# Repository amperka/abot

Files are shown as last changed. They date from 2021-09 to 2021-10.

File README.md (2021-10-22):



Amperka ROS robot "Abot" source code.

# Documentation

Detailed instructions for assembling the robot are available in Russian:

- [Как сделать робота на ROS своими руками. Часть 1: шасси и бортовая электроника](https://amperka.ru/blogs/projects/abot-robot-part-1)
- [Как сделать робота на ROS своими руками. Часть 2: дистанционное управление и навигация](https://amperka.ru/blogs/projects/abot-robot-part-2)
- [Как сделать робота на ROS своими руками. Часть 3: распознавание речи для голосового управления](https://amperka.ru/blogs/projects/abot-robot-part-3)
- [Как сделать робота на ROS своими руками. Часть 4: синтез речи и голосовое управление](https://amperka.ru/blogs/projects/abot-robot-part-4)

# Robot packages

The basis of the robot:

- `abot_description` — URDF robot description and main bringup launch files.
- `abot_driver` — Low-level drivers for working with motors and encoders on Raspberry Pi.
- `abot_control` — Robot controllers, differential drive controller.
- `abot_base` — Robot base controller.
- `abot_teleop` — Remote control of the base robot controller via the DualShock 4 joystick.
- `abot_slam` — Building 2D maps using the SLAM method and the `gmapping` package.
- `abot_navigation` — Navigation of the robot on a prepared 2D map.

Working with sound and speech on the robot:

- `abot_speech_to_text` — STT `pocketsphinx` ROS wrapper.
- `abot_text_to_speech` — TTS ROS wrappers: `RHVoice`, `festival`, AWS Polly.
- `abot_text_to_speech` — Voice control of the robot. Voice control of the navigation stack.

# Software requirements

Robot running on Ubuntu 20.04.2.0 Server arm64 and ROS Noetic and Raspberry Pi 4 B 4 Gb.

## Basis part requirements

Necessary software to run the main part of the project:

- [WiringPi](https://github.com/WiringPi/WiringPi)
- [ds4drv](https://github.com/naoki-mizuno/ds4drv)

ROS packages:

```bash
ros-noetic-gmapping
ros-noetic-joy
ros-noetic-pid
ros-noetic-map-server
ros-noetic-navigation
```

## Sound part requirements

Necessary software to run the sound part of the project:

- [GStreamer](https://en.wikipedia.org/wiki/GStreamer)
- [pocketsphinx](https://github.com/cmusphinx/pocketsphinx)
- [ru4sphinx](https://github.com/zamiron/ru4sphinx)
- [WiringPi](https://github.com/WiringPi/WiringPi)
- [TroykaHatCpp](https://github.com/amperka/TroykaHatCpp)
- [festival](https://github.com/festvox/festival)
- [RHVoice](https://github.com/RHVoice/RHVoice)
- [boto3](https://github.com/boto/boto3)
- [sox](https://github.com/chirlu/sox)

ROS packages:

```bash
ros-noetic-audio-common
ros-noetic-navigation
```

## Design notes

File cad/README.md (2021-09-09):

# Версии робота

- `ABOT_V1` - Робот первой версии. Шасси Turtle, панель Raspberry, панель лидара. Дизайн робота на момент публикации первой статьи.
- `ABOT_V2` - Робот второй версии. Шасси Turtle, панель Raspberry, панель звука, панель лидара. Дизайн робота на момент публикации второй статьи.

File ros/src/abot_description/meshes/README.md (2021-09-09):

# Версии MESH моделей

В этой папке находятся MESH модели одной из версий робота:

- `v1` - STL файлы для визуализации робота первой версии. Шасси Turtle, панель Raspberry, панель лидара.
- `v2` - STL файлы для визуализации робота второй версии. Шасси Turtle, панель Raspberry, панель звука, панель лидара.

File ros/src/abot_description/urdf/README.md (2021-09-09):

# Версии URDF описания

В этой папке находится URDF описание одной из версий робота:

- `v1` - URDF описание робота первой версии. Шасси Turtle, панель Raspberry, панель лидара.
- `v2` - URDF описание робота второй версии. Шасси Turtle, панель Raspberry, панель звука, панель лидара.

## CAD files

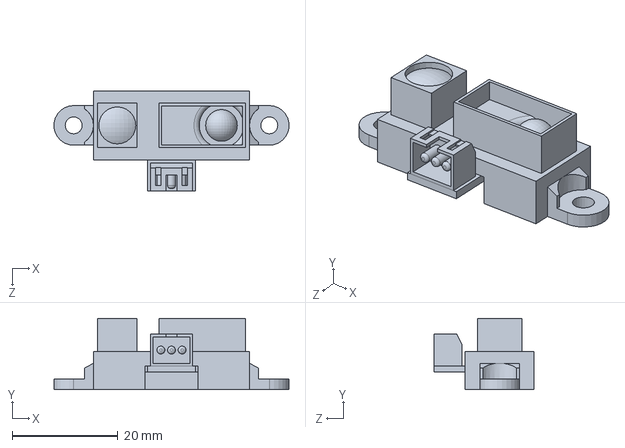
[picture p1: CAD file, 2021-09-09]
cad/SENSORS/SHARP_IR/GP2Y0A41SK0F_AXIS_FRAME.SLDASM
44.4 x 13.5 x 18.9 mm

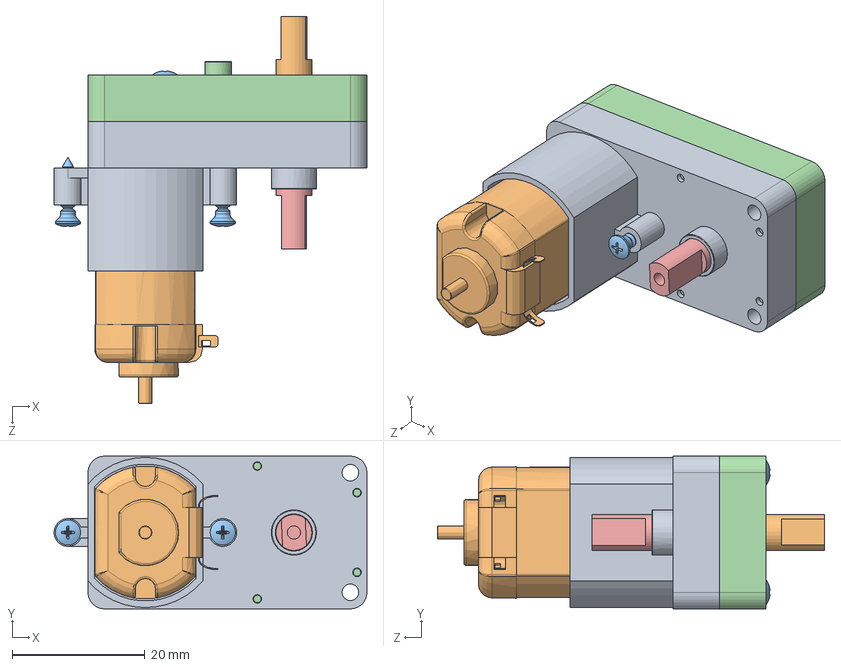
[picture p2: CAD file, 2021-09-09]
cad/MOTORS/TT_ANGLE_MOTOR.SLDASM
47.1 x 23.0 x 58.3 mm

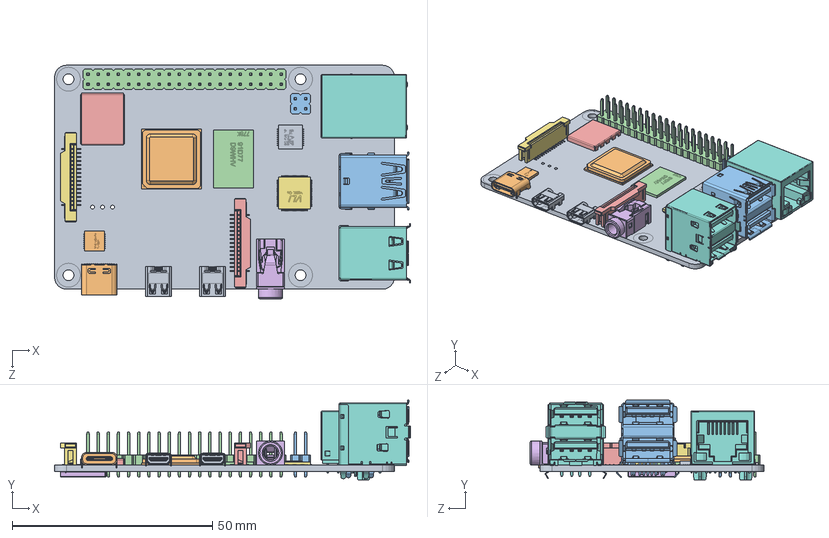
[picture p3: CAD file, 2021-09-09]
cad/ELECTRONICS/RPI/RPI/RP_4_DUMMY.SLDASM
89.0 x 19.9 x 58.4 mm
PCB, RPi4ModelB-1
Broadcom BCM2711B0 CPU, RPi4ModelB-1
2.54 mm DUPONT MALE PIN HEADER, POE, 2X2, RPi4ModelB-1
2.54 mm DUPONT MALE PIN HEADER, IO, 2X20, RPi4ModelB-1
Camera Connector, RPi4ModelB-1
Microphone Plug, RPi4ModelB-1
Display Connector, RPi4ModelB-1
Gigabit Ethernet Port, RPi4ModelB-1
Female Micro HDMI Connector, RPi4ModelB-1 x 2
Female USB Type C Connector, RPi4ModelB-1
2X USB3.0 PORTS, RPi4ModelB-1
91D77 D9WHV 778K, 4 GB LPDDR4 SDRAM, RPi4ModelB-1
Cypress CYW43455 Wireless Module Cover, RPi4ModelB-1
SD Card Slot, RPi4ModelB-1
VIA VL805 PCIe USB 3.0 controller, RPi4ModelB-1
2X USB2.0 PORTS, RPi4ModelB-1
Broadcom BCM54213PE Gigabit Ethernet Transceiver, RPi4ModelB-1
MxL7704 Universal PMIC, RPi4ModelB-1

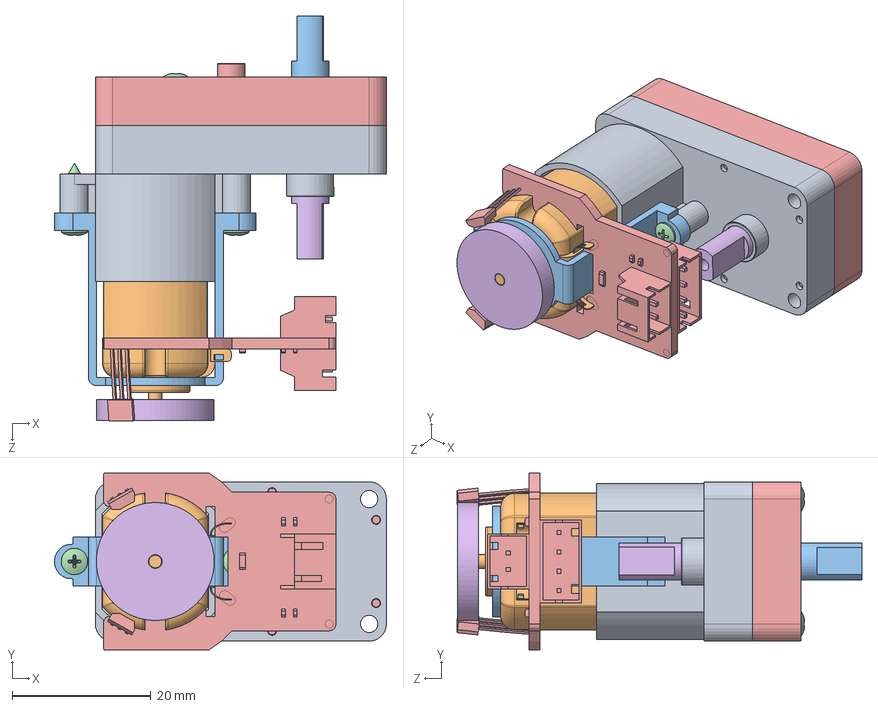
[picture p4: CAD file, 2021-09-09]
cad/MOTORS/TT_ANGLE_MOTOR_WITH_ENCODER.SLDASM
47.9 x 25.5 x 58.4 mm

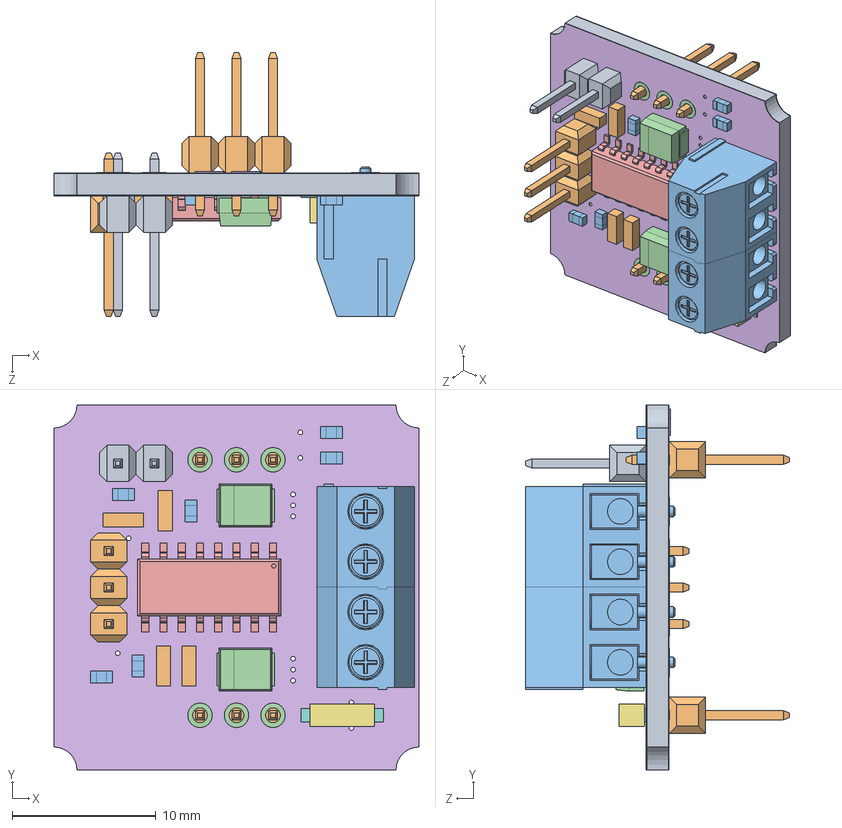
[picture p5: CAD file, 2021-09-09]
cad/ELECTRONICS/AMPERKA/TROYKA_AMPLIFIER_D/TROYKA_AMPLIFIER_D.SLDASM
25.4 x 25.4 x 18.4 mm
TROYKA_AMPLIFIER_D_Board
TROYKA_AMPLIFIER_D_C0603 x 4
TROYKA_AMPLIFIER_D_R0603 x 6
TROYKA_AMPLIFIER_D_SMC_B x 2
TROYKA_AMPLIFIER_D_SO16_SHORTPADS
TROYKA_AMPLIFIER_D_J0402 x 2
TROYKA_AMPLIFIER_D_Body
TROYKA_AMPLIFIER_D_Pins
TROYKA_AMPLIFIER_D_Model
TROYKA_AMPLIFIER_D_Model (1) x 3
TROYKA_AMPLIFIER_D_14420348.f3d x 2
TROYKA_AMPLIFIER_D_1-copper
TROYKA_AMPLIFIER_D_16-copper
TROYKA_AMPLIFIER_D_1-soldermask_1
TROYKA_AMPLIFIER_D_16-soldermask_1

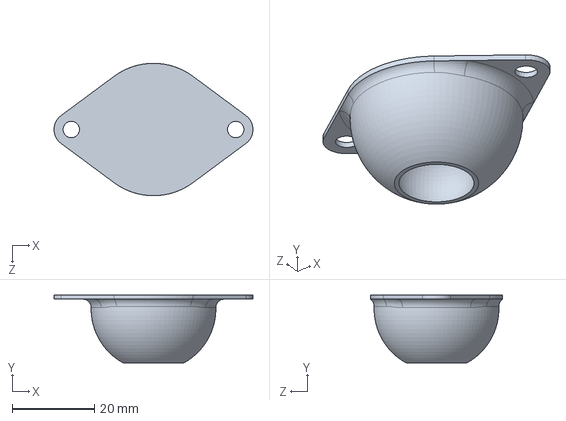
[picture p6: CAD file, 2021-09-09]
cad/CHASSIS/CASTER_WHEEL_CASE.SLDPRT
48.4 x 16.5 x 32.2 mm

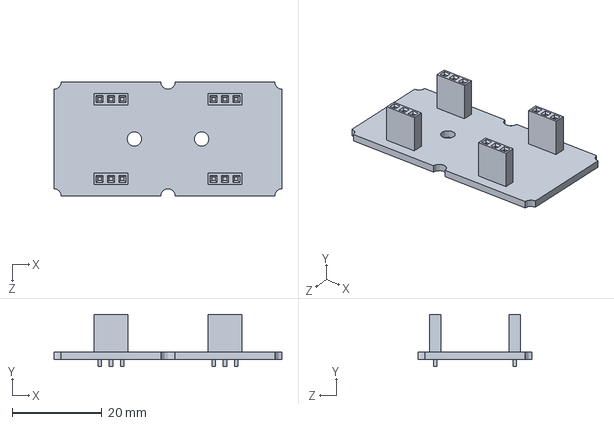
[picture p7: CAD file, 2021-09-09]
cad/ELECTRONICS/AMPERKA/TROYKA_PAD_X2_DUMMY.SLDPRT
50.8 x 11.6 x 25.4 mm

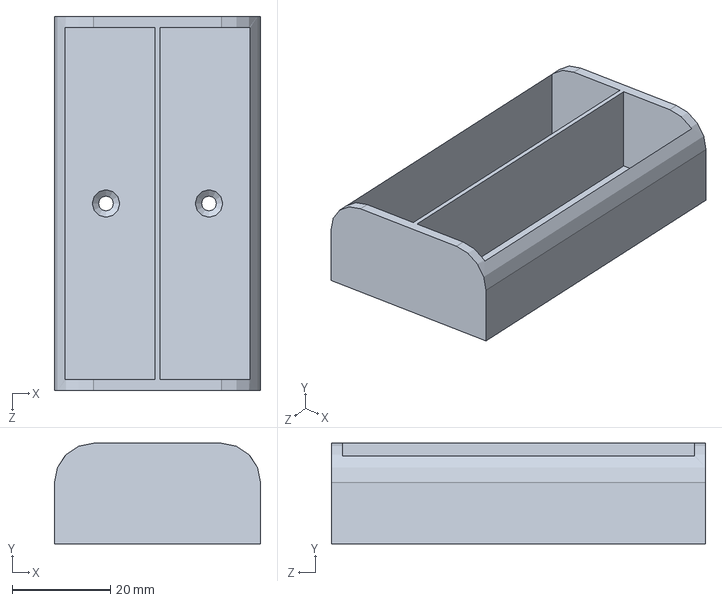
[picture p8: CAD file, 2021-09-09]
cad/ELECTRONICS/BATTERY_HOLDERS/COMMON_18650_BATTERY_HOLDER_DUMMY.SLDPRT
42.0 x 20.5 x 76.3 mm

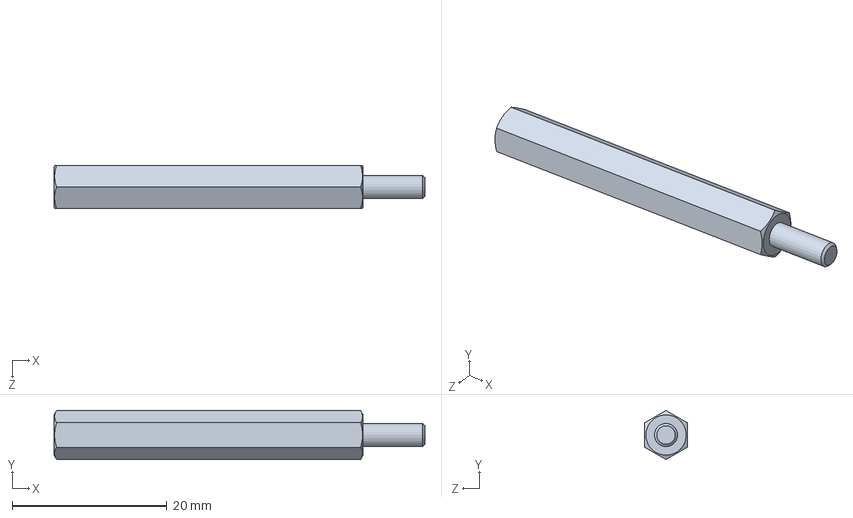
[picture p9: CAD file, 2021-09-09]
cad/METALWARE/STANDOFF_M3_40.SLDPRT
48.0 x 6.35 x 5.50 mm

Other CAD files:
cad/ELECTRONICS/AMPERKA/TROYKA_AMPLIFIER_D/TROYKA_AMPLIFIER_D__PIN_1X3.sldasm
cad/ELECTRONICS/AMPERKA/TROYKA_AMPLIFIER_D/TROYKA_AMPLIFIER_D__INDC4509X190N.sldasm
cad/ELECTRONICS/AMPERKA/TROYKA_AMPLIFIER_D/TROYKA_AMPLIFIER_D__PIN_1X3-1.sldasm
cad/ELECTRONICS/AMPERKA/TROYKA_AMPLIFIER_D/TROYKA_AMPLIFIER_D__Packages.sldasm
cad/ELECTRONICS/AMPERKA/TROYKA_AMPLIFIER_D/TROYKA_AMPLIFIER_D__SDR0302.sldasm
cad/ELECTRONICS/AMPERKA/TROYKA_AMPLIFIER_D/TROYKA_AMPLIFIER_D__PIN_1X3-2.sldasm
cad/ELECTRONICS/AMPERKA/TROYKA_AMPLIFIER_D/TROYKA_AMPLIFIER_D__PIN_1X2.sldasm
cad/ELECTRONICS/AMPERKA/TROYKA_AMPLIFIER_D/TROYKA_AMPLIFIER_D__BLM41PG102SZ1B v1.sldasm
cad/ELECTRONICS/RPI/RPI/Display Connector, RPi4ModelB-1.sldprt
cad/CHASSIS/CASTER_WHEEL_BALL.SLDPRT
cad/CHASSIS/LOWER_PLATE.SLDPRT
cad/CHASSIS/UPPER_PLATE.SLDPRT
cad/CHASSIS/WHEEL_D65_W26.SLDPRT
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

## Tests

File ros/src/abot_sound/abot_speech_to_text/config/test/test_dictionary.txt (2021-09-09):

робот
включи
выключи
зеленый
красный
светодиод
все
светодиоды
установи
яркость
красного
зеленого
светодиода
ноль
десять
двадцать
тридцать
сорок
пятьдесят
шестьдесят
семьдесят
восемьдесят
девяносто
сто

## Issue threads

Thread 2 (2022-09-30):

Не запускается abot_drivers

vdunaev, 2022-09-30:
Добрый день.
Надеюсь на вашу помощь.

Следую туториалу на amperka. Пытаюсь запустить двигатели в первый раз. Значения с датчика холла приходят, скорость, углы - все ОК.

При попытке запустить двигатели и задать скорость ничего не происходит.
А в консоли на Raspberi Pi warning:

Waiting for first setpoint message

Судя по исходникам библиотеки это из-за
!ros::topic::waitForMessage<std_msgs::Float64>(setpoint_topic_, [ros::Duration])

Уже пробовал remap менять, вручную задавать разные значения
Ничего не помогает

gabbapeople, 2022-10-01:
Привет!

Можно чуток подробнее.
- Какая OS? Какая распберри?
- Как пытаетесь запустить моторы? Каким кодом, библиотекой / нодой (через wiringPi?)
- Какой драйвер моторов (плата)
- Было бы круто более подробный лог из консоли или даже скрин

vdunaev, 2022-10-03:
@gabbapeople спасибо за ответ

- Ubuntu 20.04.5
- Raspberry Pi 4 Model B (4gb)
- Пакет 1 в 1 из репозитория abot_driver (кроме пока лидара)
`<launch>
	<node name="encoders" pkg="abot_driver" type="encoders" output="screen" />
	<node name="dc_motors" pkg="abot_driver" type="dc_motors" output="screen" />
	<include file="$(find abot_driver)/launch/abot_pid.launch" />
</launch>`
- Драйвер мотора как в статье - двухканальный Н-мост (Troyka-модуль), Troyka HAT

vdunaev, 2022-10-03:
Все шаги 1 в 1 как в статье
Значения с датчика холла приходят корректно

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

gabbapeople, 2022-10-03:
@vdunaev ну так по виду все работает.

Setpoint Warning - это пид контроллер ждет первое значение целевой скорости.
Попробуйте вручную запаблишить скорость в топики `/abot/right_wheel/target_velocity` `/abot/left_wheel/target_velocity` из консоли командой `rostopic pub --once  /abot/right_wheel/target_velocity std_msgs/Float64` и далее значение скорости в формате yaml.  Можно после  `std_msgs/Float64` нажать TAB  и ROS cкопипастит шаблон синтаксиса.

vdunaev, 2022-10-03:
Получилось только если сделать это на самом распбери.
Странно что в rqt топики видны, паблиш работает, но сообщения по факту не долетают до робота

vdunaev, 2022-10-03:
@gabbapeople большое спасибо.
Проблема была в том, что я запускаю мастер в докере (т.к. ubuntu 22 версии на локальной машине)
И не прокинул туда ROS_HOSTNAME, ROS_IP

А лишь только ROS_MASTER_URI

docker run -it --name ros --network=host --rm --env="LIBGL_ALWAYS_SOFTWARE=1" --env="ROS_MASTER_URI=http://robot-user:11311" --env="ROS_HOSTNAME=robot-user" --env="ROS_IP=192.168.0.237"  --env="DISPLAY" --env="QT_X11_NO_MITSHM=1" --volume="/tmp/.X11-unix:/tmp/.X11-unix:rw" --volume="/home/vasia/Robots/ros_src:/opt/ros/src" osrf/ros:noetic-desktop-full

В итоге заработало!

Closed 2022-10-03.

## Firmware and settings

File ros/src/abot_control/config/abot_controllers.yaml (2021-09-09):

joint_state_controller:
  type: joint_state_controller/JointStateController
  publish_rate: 100

mobile_abot:
  type : "diff_drive_controller/DiffDriveController"
  left_wheel: 'left_wheel_to_base'
  right_wheel: 'right_wheel_to_base'
  publish_rate: 100.0
  pose_covariance_diagonal: [0.001, 0.001, 1000000.0, 1000000.0, 1000000.0, 1000.0]
  twist_covariance_diagonal: [0.001, 0.001, 1000000.0, 1000000.0, 1000000.0, 1000.0]

  wheel_separation_multiplier: 1.0 # default: 1.0
  wheel_radius_multiplier    : 1.0 # default: 1.0
  cmd_vel_timeout: 1.0
  base_frame_id: base_footprint
  linear:
    x:
      has_velocity_limits : true
      max_velocity : 0.6 # m/s
      has_acceleration_limits: true
      max_acceleration : 6.0 # m/s^2
  angular:
    z:
      has_velocity_limits : true
      max_velocity : 4.71 # rad/s
      has_acceleration_limits: true
      max_acceleration : 9.42 # rad/s^2
  enable_odom_tf: true

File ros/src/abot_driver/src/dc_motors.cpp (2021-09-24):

#include "dc_motor_wiring_pi.hpp"
#include <std_msgs/Float64.h>

#define MOTOR_1_PIN_D 4 // Wiring pi 7 = BCM 4
#define MOTOR_1_PIN_E 18 // Wiring pi 1 = BCM 18
#define MOTOR_2_PIN_D 12 // Wiring pi 26 = BCM 12
#define MOTOR_2_PIN_E 13 // Wiring pi 23 = BCM 13

DCMotorWiringPi left_dc_motor(MOTOR_1_PIN_D, MOTOR_1_PIN_E);
DCMotorWiringPi right_dc_motor(MOTOR_2_PIN_D, MOTOR_2_PIN_E);

void leftMotorCallback(const std_msgs::Float64& msg) {
	int16_t pwm = msg.data * 100;
	if (pwm > 0) {
		left_dc_motor.ccw(abs(pwm));
	} else if (pwm < 0) {
		left_dc_motor.cw(abs(pwm));
	} else if (pwm == 0) {
		left_dc_motor.stop();
	}
}

void rightMotorCallback(const std_msgs::Float64& msg) {
	int16_t pwm = msg.data * 100;
	if (pwm > 0) {
		right_dc_motor.ccw(abs(pwm));
	} else if (pwm < 0) {
		right_dc_motor.cw(abs(pwm));
	} else if (pwm == 0) {
		right_dc_motor.stop();
	}
}

int main(int argc, char** argv) {
	ros::init(argc, argv, "dc_motors");
	ros::NodeHandle node;
	ros::Subscriber left_motor_target_vel_sub = node.subscribe("/abot/left_wheel/pwm", 1, &leftMotorCallback);
	ros::Subscriber right_motor_target_vel_sub = node.subscribe("/abot/right_wheel/pwm", 1, &rightMotorCallback);
	ros::spin();
	return 0;
}

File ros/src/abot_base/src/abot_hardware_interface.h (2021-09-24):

#ifndef ABOT_HARDWARE_INTERFACE_HPP_
#define ABOT_HARDWARE_INTERFACE_HPP_

#include <boost/assign/list_of.hpp>
#include <sstream>
#include <std_msgs/Float64.h>
#include <std_srvs/Empty.h>

#include <controller_manager/controller_manager.h>
#include <hardware_interface/joint_command_interface.h>
#include <hardware_interface/joint_state_interface.h>
#include <hardware_interface/robot_hw.h>
#include <ros/console.h>
#include <ros/ros.h>

class AbotHardwareInterface : public hardware_interface::RobotHW {
public:
	AbotHardwareInterface(ros::NodeHandle node, ros::NodeHandle private_node, double target_max_wheel_angular_speed);

	void updateJointsFromHardware(const ros::Duration& period);
	void writeCommandsToHardware();

private:
	ros::NodeHandle _node;
	ros::NodeHandle _private_node;

	hardware_interface::JointStateInterface _joint_state_interface;
	hardware_interface::VelocityJointInterface _velocity_joint_interface;

	ros::Subscriber _left_wheel_angle_sub;
	ros::Subscriber _right_wheel_angle_sub;
	ros::Publisher _left_wheel_vel_pub;
	ros::Publisher _right_wheel_vel_pub;

	struct Joint {
		double position;
		double position_offset;
		double velocity;
		double effort;
		double velocity_command;

		Joint()
			: position(0)
			, velocity(0)
			, effort(0)
			, velocity_command(0) { }
	} _joints[2];

	double _left_wheel_angle;
	double _right_wheel_angle;
	double _max_wheel_angular_speed;

	void registerControlInterfaces();
	void leftWheelAngleCallback(const std_msgs::Float64& msg);
	void rightWheelAngleCallback(const std_msgs::Float64& msg);
	void limitDifferentialSpeed(double& diff_speed_left_side, double& diff_speed_right_side);
};

AbotHardwareInterface::AbotHardwareInterface(ros::NodeHandle node, ros::NodeHandle private_node, double target_max_wheel_angular_speed)
	: _node(node)
	, _private_node(private_node)
	, _max_wheel_angular_speed(target_max_wheel_angular_speed) {
	registerControlInterfaces();

	_left_wheel_vel_pub = _node.advertise<std_msgs::Float64>("/abot/left_wheel/target_velocity", 1);
	_right_wheel_vel_pub = _node.advertise<std_msgs::Float64>("/abot/right_wheel/target_velocity", 1);
	_left_wheel_angle_sub = _node.subscribe("abot/left_wheel/angle", 1, &AbotHardwareInterface::leftWheelAngleCallback, this);
	_right_wheel_angle_sub = _node.subscribe("abot/right_wheel/angle", 1, &AbotHardwareInterface::rightWheelAngleCallback, this);
}

void AbotHardwareInterface::writeCommandsToHardware() {
	double diff_angle_speed_left = _joints[0].velocity_command;
	double diff_angle_speed_right = _joints[1].velocity_command;

	limitDifferentialSpeed(diff_angle_speed_left, diff_angle_speed_right);

	std_msgs::Float64 left_wheel_vel_msg;
	std_msgs::Float64 right_wheel_vel_msg;

	left_wheel_vel_msg.data = diff_angle_speed_left;
	right_wheel_vel_msg.data = diff_angle_speed_right;

	_left_wheel_vel_pub.publish(left_wheel_vel_msg);
	_right_wheel_vel_pub.publish(right_wheel_vel_msg);
}

void AbotHardwareInterface::updateJointsFromHardware(const ros::Duration& period) {
	double delta_left_wheel = _left_wheel_angle - _joints[0].position - _joints[0].position_offset;
	double delta_right_wheel = _right_wheel_angle - _joints[1].position - _joints[1].position_offset;

	if (std::abs(delta_left_wheel) < 1) {
		_joints[0].position += delta_left_wheel;
		_joints[0].velocity = delta_left_wheel / period.toSec();
	} else {
		_joints[0].position_offset += delta_left_wheel;
	}

	if (std::abs(delta_right_wheel) < 1) {
		_joints[1].position += delta_right_wheel;
		_joints[1].velocity = delta_right_wheel / period.toSec();
	} else {
		_joints[1].position_offset += delta_right_wheel;
	}
}

void AbotHardwareInterface::registerControlInterfaces() {
	ros::V_string joint_names = boost::assign::list_of("left_wheel_to_base")("right_wheel_to_base");

	for (unsigned int i = 0; i < joint_names.size(); i++) {
		hardware_interface::JointStateHandle joint_state_handle(joint_names[i], &_joints[i].position, &_joints[i].velocity, &_joints[i].effort);
		_joint_state_interface.registerHandle(joint_state_handle);

		hardware_interface::JointHandle joint_handle(joint_state_handle, &_joints[i].velocity_command);
		_velocity_joint_interface.registerHandle(joint_handle);
	}
	registerInterface(&_joint_state_interface);
	registerInterface(&_velocity_joint_interface);
}

void AbotHardwareInterface::leftWheelAngleCallback(const std_msgs::Float64& msg) {
	_left_wheel_angle = msg.data;
}

void AbotHardwareInterface::rightWheelAngleCallback(const std_msgs::Float64& msg) {
	_right_wheel_angle = msg.data;
}

void AbotHardwareInterface::limitDifferentialSpeed(double& diff_speed_left_side, double& diff_speed_right_side) {
	double large_speed = std::max(std::abs(diff_speed_left_side), std::abs(diff_speed_right_side));
	if (large_speed > _max_wheel_angular_speed) {
		diff_speed_left_side *= _max_wheel_angular_speed / large_speed;
		diff_speed_right_side *= _max_wheel_angular_speed / large_speed;
	}
}

#endif // ABOT_HARDWARE_INTERFACE_HPP_

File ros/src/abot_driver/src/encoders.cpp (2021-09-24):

#include "encoder_wiring_pi.hpp"
#include <chrono>
#include <std_msgs/Float64.h>

typedef boost::chrono::steady_clock time_source;

class EncodersPair {
public:
	EncodersPair(double update_rate);

private:
	ros::NodeHandle node;

	ros::Publisher left_wheel_angle_pub;
	ros::Publisher right_wheel_angle_pub;
	ros::Publisher left_wheel_velocity_pub;
	ros::Publisher right_wheel_velocity_pub;

	ros::Timer encoders_timer;

	std_msgs::Float64 left_wheel_angle_msg;
	std_msgs::Float64 right_wheel_angle_msg;
	std_msgs::Float64 left_wheel_velocity_msg;
	std_msgs::Float64 right_wheel_velocity_msg;

	EncoderWiringPi encoder_left;
	EncoderWiringPi encoder_right;

	double left_wheel_angle;
	double right_wheel_angle;
	double left_wheel_velocity;
	double right_wheel_velocity;
	double left_wheel_position;
	double right_wheel_position;

	time_source::time_point last_time;

	void encodersCallback(const ros::TimerEvent& event);
};

EncodersPair::EncodersPair(double update_rate)
	: encoder_left(ENCODER_1_PIN_A, ENCODER_1_PIN_B, &EncoderWiringPiISR::encoderISR1, &EncoderWiringPiISR::encoderPosition1)
	, encoder_right(ENCODER_2_PIN_A, ENCODER_2_PIN_B, &EncoderWiringPiISR::encoderISR2, &EncoderWiringPiISR::encoderPosition2) {
	left_wheel_angle_pub = node.advertise<std_msgs::Float64>("/abot/left_wheel/angle", 1);
	right_wheel_angle_pub = node.advertise<std_msgs::Float64>("/abot/right_wheel/angle", 1);
	left_wheel_velocity_pub = node.advertise<std_msgs::Float64>("/abot/left_wheel/current_velocity", 1);
	right_wheel_velocity_pub = node.advertise<std_msgs::Float64>("/abot/right_wheel/current_velocity", 1);

	encoders_timer = node.createTimer(ros::Duration(update_rate), &EncodersPair::encodersCallback, this);
}

void EncodersPair::encodersCallback(const ros::TimerEvent& event) {
	time_source::time_point this_time = time_source::now();
	boost::chrono::duration<double> elapsed_duration = this_time - last_time;
	ros::Duration elapsed(elapsed_duration.count());
	last_time = this_time;

	left_wheel_angle = -1 * encoder_left.getAngle();
	right_wheel_angle = 1 * encoder_right.getAngle();

	left_wheel_angle_msg.data = left_wheel_angle;
	right_wheel_angle_msg.data = right_wheel_angle;

	left_wheel_angle_pub.publish(left_wheel_angle_msg);
	right_wheel_angle_pub.publish(right_wheel_angle_msg);

	double delta_left_wheel = left_wheel_angle - left_wheel_position;
	double delta_right_wheel = right_wheel_angle - right_wheel_position;

	left_wheel_position += delta_left_wheel;
	left_wheel_velocity = delta_left_wheel / elapsed.toSec();

	right_wheel_position += delta_right_wheel;
	right_wheel_velocity = delta_right_wheel / elapsed.toSec();

	left_wheel_velocity_msg.data = left_wheel_velocity;
	right_wheel_velocity_msg.data = right_wheel_velocity;

	left_wheel_velocity_pub.publish(left_wheel_velocity_msg);
	right_wheel_velocity_pub.publish(right_wheel_velocity_msg);
}

int main(int argc, char** argv) {
	ros::init(argc, argv, "encoders");
	EncodersPair encoders_pair(0.01);
	ros::spin();
	return 0;
}

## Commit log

2021-09-09 feat: Add robot source code
    [1.SLDPRT, 10.SLDPRT, 11.SLDPRT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]
2021-09-09 feat: Massive update, sound part
    [2.54 mm DUPONT MALE PIN HEADER, IO, 2X20, RPi4ModelB-1.sldprt, 2.54 mm DUPONT MALE PIN HEADER, POE, 2X2, RPi4ModelB-1.sldprt, 2X USB2.0 PORTS, RPi4ModelB-1.sld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]
